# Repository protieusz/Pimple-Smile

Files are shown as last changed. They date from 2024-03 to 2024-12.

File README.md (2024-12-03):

# Pimple-Smile
Pimple Smile, an upgraded [Smile36](https://github.com/protieusz/Smile36-PCB-Version) with a 25mm integrated trackball with no encoders. Full PLA designed case with integrated 5mm thick switch plate. Integrated trackball support to the switch plate.

~~Pimple Smile will be close source as this design will go on sale.~~  PCB is currently in transit for prototype build.
Pimple Smile will use a Waveshare RP2040 Zero mcu following its predecessor, the Smile36. WS RP2040 Zero will be smd solder onto the keyboard PCB. The footprints allows for thru hole soldering but I have not tested out if the soldered mcu with the headers will enough room to fit the case. Test out at your own risk.

For the top case, I have cut 0.2mm at the sensor area for some extra tolerance so you can push the sensor lens up a little bit if the ball is not moving and tap the sensor plastic with tape from the bottom.  This has not been fully tested. But print at your own risk. Some PLA printers have better accuracy than others. ~~Mill Max is not recommended since the gap will interfere with the trackball sensor.~~ You can Mill Max it and no issues with the trackball sensor. I have tested it. Top case switch square hole notches were done by Plant of MechWild.

Even though these files are public. Please use them as your own risk. No support will be given.

# Featured On https://kbd.news/Pimple-Smile-2378.html

# Full Production

0FA4429B-2CC0-479B-98AB-1A03A988E413
B45F2E86-E520-4D3F-AB1D-F5F5C0AD66DA
























Salvaging From Old Smile36, My Very First PCB Prototype






EasyEDA Render

Screenshot 2024-03-09 at 3 35 16 PM
Screenshot 2024-03-09 at 3 34 59 PM
Screenshot 2024-03-09 at 3 34 28 PM
Screenshot 2024-03-09 at 3 34 15 PM
Screenshot 2024-03-09 at 3 34 05 PM
Screenshot 2024-03-09 at 3 33 50 PM
Screenshot 2024-03-09 at 3 33 20 PM
Screenshot 2024-03-09 at 12 39 29 PM

# License

</a></p>

You are free to:

Share — copy and redistribute the material in any medium or format

Adapt — remix, transform, and build upon the material

The licensor cannot revoke these freedoms as long as you follow the license terms.
Under the following terms:

Attribution — You must give appropriate credit, provide a link to the license, and indicate if changes were made. You may do so in any reasonable manner, but not in any way that suggests the licensor endorses you or your use.

NonCommercial — You may not use the material for commercial purposes.

ShareAlike — If you remix, transform, or build upon the material, you must distribute your contributions under the same license as the original.

No additional restrictions — You may not apply legal terms or technological measures that legally restrict others from doing anything the license permits.

Pimple Smile by ProtieusKeebs is licensed under [CC BY-NC-SA 4.0](https://creativecommons.org/licenses/by-nc-sa/4.0/?ref=chooser-v1)

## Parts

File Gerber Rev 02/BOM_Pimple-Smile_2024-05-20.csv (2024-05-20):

ID | Name | Designator | Footprint | Quantity | Manufacturer Part | Manufacturer | Supplier | Supplier Part | Price | link
1 | DIODE-SOD123 | D100,D101,D102,D103,D104,D105,D106,D107,D108,D109,D200,D201,D202,D203,D204,D205,D206,D207,D208,D209,D000,D001,D002,D003,D004,D005,D006,D007,D008,D009,D300,D301,D303,D306,D308,D309 | DIODE-SOD123 | 36
2 | PMW3360DM-T2QU | U11 | PMW3360DM-T2QU.PACK | 1 | PMW3360DM-T2QU |  |  |  |  | http://www.pixart.com/upload/PMS0058-PMW3360DM-T2QU-NNDS-R1.30-06042016_20160902201411.pdf
3 | 4.7uF | C17,C19,C20 | C0402 | 3 | CL05A475MP5NRNC | SAMSUNG(三星) | LCSC | C23733 | 0.005 | https://lcsc.com/eda_search?q=C23733&%26type=1&ref=editor
4 | 100nF | C18 | C0402 | 1 | CL05B104KB54PNC | SAMSUNG(三星) | LCSC | C307331 | 0.005 | https://lcsc.com/eda_search?q=C307331&%26type=1&ref=editor
5 | 10kΩ | R10,R12,R13 | R0402 | 3 | 0402WGF1002TCE | UNI-ROYAL(厚声) | LCSC | C25744 | 0.001 | https://lcsc.com/eda_search?q=C25744&%26type=1&ref=editor
6 | 39Ω | R11 | R0402 | 1 | 0402WGJ0390TCE | UNI-ROYAL(厚声) | LCSC | C25164 |  | https://lcsc.com/eda_search?q=C25164&%26type=1&ref=editor
7 | 15kΩ | R14 | R0402 | 1 | 0402WGF1502TCE | UNI-ROYAL(厚声) | LCSC | C25756 | 0.001 | https://lcsc.com/eda_search?q=C25756&%26type=1&ref=editor
8 | AP2127K-ADJTRG1 | U10 | SOT-23-5_L3.0-W1.7-P0.95-LS2.8-BR | 1 | AP2127K-ADJTRG1 | DIODES(美台) | LCSC | C96343 | 0.07 | https://lcsc.com/eda_search?q=C96343&%26type=1&ref=editor
9 | Switch | K100,K200,K300,K309,K009 | CHERRY_MX_125_MILLMAX | 5
10 | Switch | K000,K001,K002,K003,K004,K005,K006,K007,K008,K101,K102,K103,K104,K105,K106,K107,K108,K109,K201,K202,K203,K204,K205,K206,K207,K208,K209,K301,K308 | CHERRY_MX_100_MILLMAX | 29
11 | Switch | K303,K306 | CHERRY_MX_175_MILLMAX | 2
12 | RP2040-ZERO_WAVESHARE - with GPIO | U1 | RP2040-ZERO_WAVESHARE- W/ GPIO | 1

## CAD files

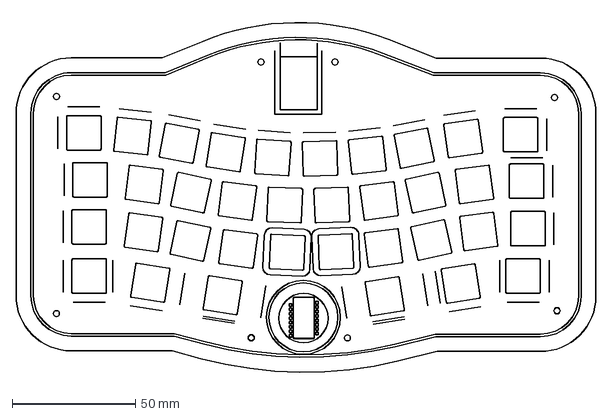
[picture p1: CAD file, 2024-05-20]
PimpleSmilePCB.dxf
235.2 x 146.2 mm

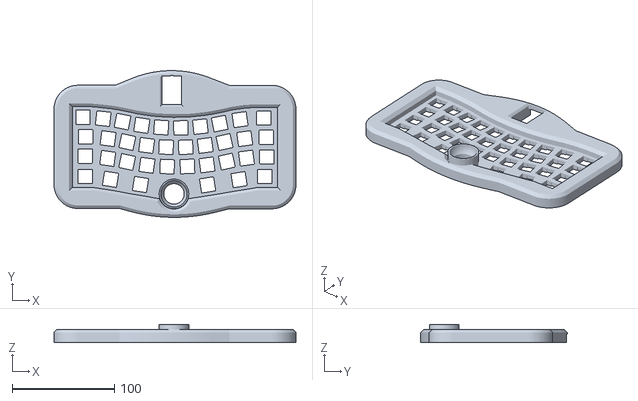
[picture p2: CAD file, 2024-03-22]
STLs/Pimple Smile ThickTopPlate 0.2mm clearance.stl
237.2 x 143.8 x 17.8

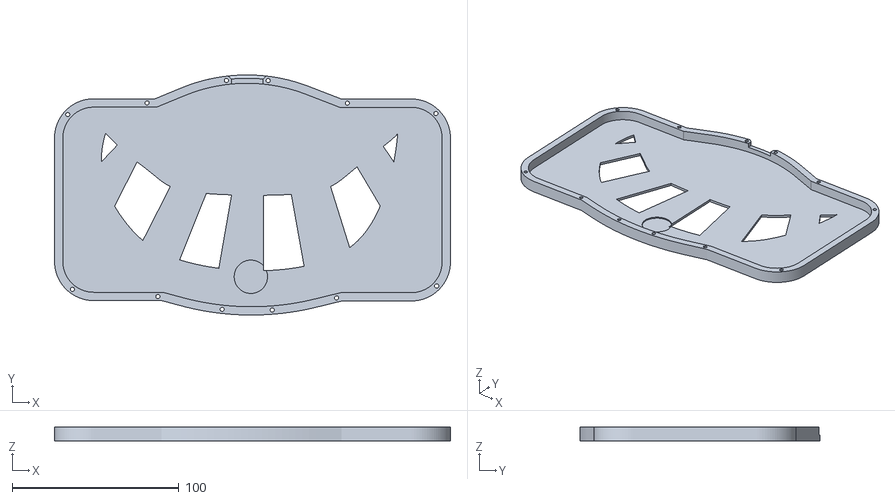
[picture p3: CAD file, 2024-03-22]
STLs/Pimple Smile Bottom 3mm short.stl
237.2 x 143.8 x 8.20

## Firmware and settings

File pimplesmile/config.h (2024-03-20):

// Copyright 2023 aki27 (@aki27kbd)
// SPDX-License-Identifier: GPL-2.0-or-later

#pragma once

//#define VIAL_KEYBOARD_UID {0xC4, 0x18, 0xCC, 0x6D, 0x1C, 0x16, 0x5B, 0x8D}
//#define VIAL_UNLOCK_COMBO_ROWS {0, 0}
//#define VIAL_UNLOCK_COMBO_COLS {1, 11}

/* VIA */
//#define DYNAMIC_KEYMAP_LAYER_COUNT 8


/* key matrix size */
//#define MATRIX_COLS 13
//#define MATRIX_ROWS 4


/* tapping term */
// #define TAPPING_FORCE_HOLD
//#define TAPPING_TERM 200
// #define IGNORE_MOD_TAP_INTERRUPT

#define RP2040_BOOTLOADER_DOUBLE_TAP_RESET // Activates the double-tap behavior
#define RP2040_BOOTLOADER_DOUBLE_TAP_RESET_TIMEOUT 200U // Timeout window in ms in which the double tap can occur.

#ifdef COMBO_ENABLE
#    define COMBO_COUNT 2
#    define COMBO_TERM 200
#endif

/* Encoder */
//#define ENCODERS_PAD_A { GP11 }
//#define ENCODERS_PAD_B { GP12 }
//#define ENCODER_RESOLUTION 4

/* Matrix*/
//#define MATRIX_COL_PINS { GP25, GP24, GP23, GP22, GP21, GP26, GP27, GP20, GP19, GP18, GP17, GP16, GP13 }
//#define MATRIX_ROW_PINS { GP28, GP10, GP14, GP15 }

/* COL2ROW, ROW2COL */
//#define DIODE_DIRECTION COL2ROW


/* Set 0 if debouncing isn't needed */
//#define DEBOUNCE 5


/* Mechanical locking support. Use KC_LCAP, KC_LNUM or KC_LSCR instead in keymap (Very Important for Scroll Lock!!!) */
#undef LOCKING_SUPPORT_ENABLE
/* Locking resynchronize hack */
#undef LOCKING_RESYNC_ENABLE


/* RGB LED */
//#define WS2812_PIO_USE_PIO1
//#define WS2812_DI_PIN GP0

//#ifdef RGBLIGHT_ENABLE
    //#define RGBLIGHT_LED_COUNT 6
    //#define RGBLIGHT_LIMIT_VAL 80
    //#define RGBLIGHT_HUE_STEP 10
    //#define RGBLIGHT_SAT_STEP 17
    //#define RGBLIGHT_VAL_STEP 17

    //#define RGBLIGHT_EFFECT_BREATHING
    //#define RGBLIGHT_EFFECT_RAINBOW_MOOD
    //#define RGBLIGHT_EFFECT_RAINBOW_SWIRL
    //#define RGBLIGHT_EFFECT_SNAKE
    //#define RGBLIGHT_EFFECT_KNIGHT
    //#define RGBLIGHT_EFFECT_CHRISTMAS
    //#define RGBLIGHT_EFFECT_STATIC_GRADIENT
    //#define RGBLIGHT_EFFECT_TWINKLE
    //#define RGBLIGHT_EFFECT_ALTERNATING
//#endif


/* Trackball */

#ifdef POINTING_DEVICE_ENABLE

//#    undef RP_SPI_USE_SPI0
//#    define RP_SPI_USE_SPI0 TRUE
//#    undef RP_SPI_USE_SPI1
//#    define RP_SPI_USE_SPI1 FALSE
#    define SPI_DRIVER SPID1

//#    define SPI_SCK_PIN GP22 //6
//#    define SPI_MISO_PIN GP24 //4
//#    define SPI_MOSI_PIN GP23 //7
#    define SPI_SCK_PIN GP14
#    define SPI_MISO_PIN GP12
#    define SPI_MOSI_PIN GP15

#endif


#ifndef PMW33XX_CS_PIN
#    define PMW33XX_CS_PIN GP13
#endif
//#define POINTING_DEVICE_INVERT_X
//#define POINTING_DEVICE_INVERT_Y
//#define ROTATIONAL_TRANSFORM_ANGLE 90
//#define POINTING_DEVICE_ROTATION_90

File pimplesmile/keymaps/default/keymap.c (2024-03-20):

/*
Copyright 2022 aki27

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
You should have received a copy of the GNU General Public License
along with this program.  If not, see <http://www.gnu.org/licenses/>.
*/

#include QMK_KEYBOARD_H

enum combo_events {
  COMBO_DEL,
  COMBO_ESC,
  //COMBO_RCLICK,
  COMBO_LENGTH
};
uint16_t COMBO_LEN = COMBO_LENGTH;

const uint16_t PROGMEM combo_del[] = {KC_Y, KC_H, COMBO_END};
const uint16_t PROGMEM combo_esc[] = {KC_T, KC_G, COMBO_END};
//const uint16_t PROGMEM combo_rclick[] = {KC_MS_BTN1, SCRL_MO, COMBO_END};

combo_t key_combos[] = {
  [COMBO_DEL] = COMBO(combo_del, KC_DEL),
  [COMBO_ESC] = COMBO(combo_esc, KC_ESC),
  //[COMBO_RCLICK] = COMBO(combo_rclick, KC_MS_BTN2),
};

layer_state_t layer_state_set_user(layer_state_t state) {
    return update_tri_layer_state(state, 1, 2, 3);
} 

enum layer_names {
  _BASE,
  _FN1,
  _FN2,
  _FN3
};

const uint16_t PROGMEM keymaps[][MATRIX_ROWS][MATRIX_COLS] = {
    
    [_BASE] = LAYOUT(
        KC_Q,         KC_W, KC_E,    KC_R,    KC_T,                            KC_Y,   KC_U,        KC_I,     KC_O,     KC_P,
        KC_A,         KC_S, KC_D,    KC_F,    KC_G,                            KC_H,   KC_J,        KC_K,     KC_L,     KC_SCLN,
        LSFT_T(KC_Z), KC_X, KC_C,    KC_V,    KC_B,                            KC_N,   KC_M,        KC_COMMA, KC_DOT,   RSFT_T(KC_SLSH),
        KC_LGUI,      KC_LCTL,       LT(1,KC_BSPC),                                    LT(2,KC_SPC),          (KC_ENT), KC_LALT
    ),
    [_FN1] = LAYOUT(
        KC_1,    KC_2,    KC_3,    KC_4,    KC_5,                              KC_6,     KC_7,    KC_8,    KC_9,    KC_0,
        KC_TAB,  _______, KC_MUTE, KC_VOLD, KC_VOLU,                           KC_MINS,  KC_EQL,  KC_LBRC, KC_RBRC, KC_QUOT,
        _______, SCRL_MO, KC_MS_BTN2, KC_MS_BTN1, _______,                     KC_TILD,  KC_GRV,  _______, _______, KC_BSLS,
        _______, _______,          _______,                                             _______,           _______, _______
    ),
    [_FN2] = LAYOUT(
        KC_EXLM,  KC_AT,    KC_HASH,  KC_DLR,  KC_PERC,                        KC_CIRC,  KC_AMPR, KC_ASTR, KC_LPRN, KC_RPRN,
        RGB_VAI,  RGB_SAI,  RGB_HUI,  RGB_SPI, RGB_MOD,                        RGB_TOG,  _______, _______, _______, _______,
        RGB_VAD,  RGB_SAD,  RGB_HUD,  RGB_SPD, RGB_RMOD,                       _______,  _______, _______, _______, _______,
        _______, _______,             _______,                                           _______,          _______, _______
    ),
    [_FN3] = LAYOUT(
        _______, KC_UP,   _______, _______, _______,                           KC_F1,   KC_F2,   KC_F3,   KC_F4,   KC_PSCR,
        KC_LEFT, KC_DOWN, KC_RIGHT,_______, _______,                           KC_F5,   KC_F6,   KC_F7,   KC_F8,   KC_F9,
        _______, _______, ROT_L15, ROT_R15, CPI_SW,                            KC_F10,  KC_F11,  KC_F12,  _______, _______,
        _______,                   _______, _______,                                    _______,          _______, _______
    )
};

//bool encoder_update_user(uint8_t index, bool clockwise) {
    //if (index == 0) {
        //if (clockwise) {
            //tap_code(KC_VOLD);
            //tap_code(KC_MS_WH_UP);
        //} else {
            //tap_code(KC_VOLU);
            //tap_code(KC_MS_WH_DOWN);
        //}
    //}
    //return true;
//}

//#if defined(ENCODER_MAP_ENABLE)
//const uint16_t PROGMEM encoder_map[][NUM_ENCODERS][2] = {
    //[0] =  { ENCODER_CCW_CW(KC_MS_WH_UP, KC_MS_WH_DOWN)  },
    //[1] =  { ENCODER_CCW_CW(KC_MS_WH_LEFT, KC_MS_WH_RIGHT)  },
    //[2] =  { ENCODER_CCW_CW(KC_PGUP, KC_PGDN)  },
    //[3] =  { ENCODER_CCW_CW(KC_VOLD, KC_VOLU)  } 
    //[4] =  { ENCODER_CCW_CW(XXXXXXX, XXXXXXX) }
//};
//#endif

//keyevent_t encoder1_ccw = {
    //.key = (keypos_t){.row = 3, .col = 0},
    //.pressed = false
//};

//keyevent_t encoder1_cw = {
    //.key = (keypos_t){.row = 3, .col = 9},
    //.pressed = false
//};

//bool encoder_update_user(uint8_t index, bool clockwise) {
    //if (index == 0) { /* First encoder */
        //if (clockwise) {
            //encoder1_cw.pressed = true;
            //encoder1_cw.time = (timer_read() | 1);
            //action_exec(encoder1_cw);
        //} else {
            //encoder1_ccw.pressed = true;
            //encoder1_ccw.time = (timer_read() | 1);
            //action_exec(encoder1_ccw);
        //}
    //}

    //return true;
//}

//void matrix_scan_user(void) {

    //if (IS_PRESSED(encoder1_ccw)) {
        //encoder1_ccw.pressed = false;
        //encoder1_ccw.time = (timer_read() | 1);
        //action_exec(encoder1_ccw);
    //}

    //if (IS_PRESSED(encoder1_cw)) {
        //encoder1_cw.pressed = false;
        //encoder1_cw.time = (timer_read() | 1);
        //action_exec(encoder1_cw);
    //}

//}

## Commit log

2024-03-22 Case STLs
    [Pimple Smile Bottom 3mm short.stl, Pimple Smile ThickTopPlate 0.2mm clearance.stl]
2024-05-20 PCB DXF
    [PimpleSmilePCB.dxf]

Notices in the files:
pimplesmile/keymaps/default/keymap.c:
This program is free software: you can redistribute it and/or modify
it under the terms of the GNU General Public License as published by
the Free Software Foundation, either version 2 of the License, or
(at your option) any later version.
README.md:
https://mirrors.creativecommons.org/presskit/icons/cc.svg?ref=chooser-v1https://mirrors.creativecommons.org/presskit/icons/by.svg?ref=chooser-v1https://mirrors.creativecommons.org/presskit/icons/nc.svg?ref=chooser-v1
